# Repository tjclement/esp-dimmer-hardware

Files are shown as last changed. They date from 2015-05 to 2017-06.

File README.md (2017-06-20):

# $5 ESP8266 WiFi LED Dimmer
Custom hardware designs for a super tiny WiFi LED dimmer module based on the ESP8266, to control your lights from any device. __Doesn't need any arduinos or raspberries to work, just the ESP__. If you like this, please give it a star!

__Update:__ The new module design for RGB (i.e. triple channel) LEDs is done. This new design can handle up to ~8.5A of current per channel! Its parts costs the same as the old design, and if you want only one channel, you could just not solder the 2nd and 3rd channel. This way you can use the beefed up design. :)

<p align="center">
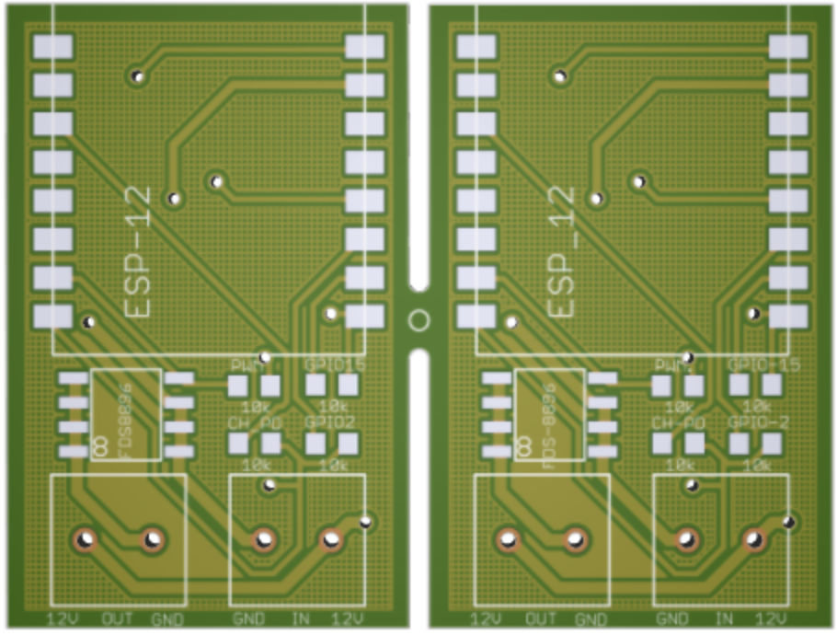
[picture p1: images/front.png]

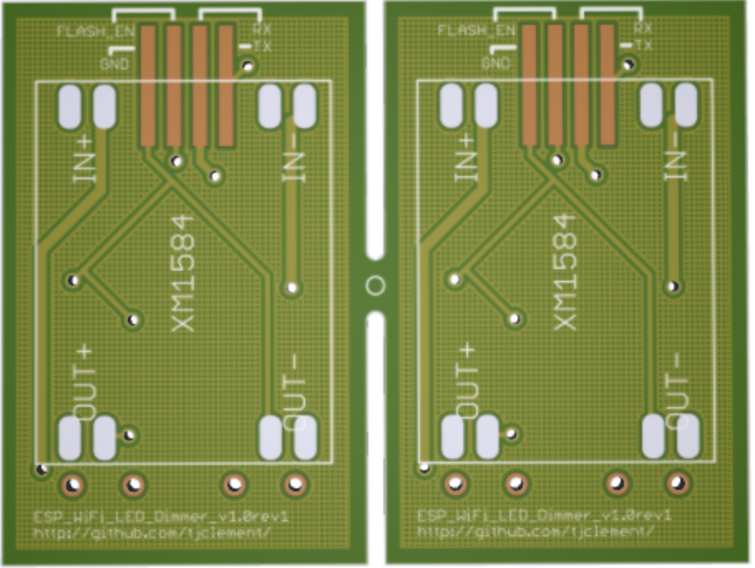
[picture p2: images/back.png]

</p>
<p align="center">
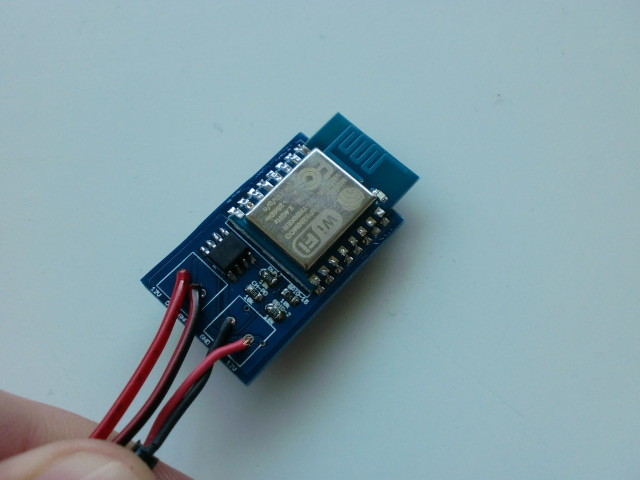
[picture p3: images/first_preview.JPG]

</p>

# Ordering the board
Choose whether you want a single or triple channel dimmer, and then send all files in [single_channel or triple_channel]/gerber_files/ to your PCB house, and all should be fine and dandy!

You can also order the new triple channel design from DirtyPCBs here: 
http://dirtypcbs.com/store/designer/details/tjclement/1329/5-esp8266-rgb-led-dimmer

# Parts
After having ordered the print board, you're going to want to have these parts for every module (mind you, there's two panelized modules per board ordered!):
<table>
  <tr>
    <td colspan="2"><strong>Single Channel (old version)</strong></td>
    <td colspan="2"><strong>Triple Channel (new version)</strong></td>
  </tr>
  <tr>
    <td>Amount</td>
    <td>Description</td>
    <td>Amount</td>
    <td>Description</td>
  </tr>
  <tr>
    <td>1</td>
    <td>ESP8266, ESP-12(E) format</td>
    <td>1</td>
    <td>ESP8266, ESP-12(E) format</td>
  </tr>
  <tr>
    <td>1</td>
    <td>XM1584 Power converter (set to 3.3v!)</td>
    <td>1</td>
    <td>MP2307 MINI 360 Power converter (3.3v!)</td>
  </tr>
  <tr>
    <td>1</td>
    <td>FDS8896 PowerTrench MOSFET</td>
    <td>3</td>
    <td>FDS8896 PowerTrench MOSFET</td>
  </tr>
  <tr>
    <td>2</td>
    <td>KF350-2P screw terminal blocks</td>
    <td>4</td>
    <td>KF350-2P screw terminal blocks</td>
  </tr>
  <tr>
    <td>4</td>
    <td>10k resistors, 0603 format</td>
    <td>6</td>
    <td>10k resistors, 0603 format</td>
  </tr>
</table>

__Total cost: less than $5!__

I order most of it from China, sites like aliexpress.com will have everything you need.

# Firmware
Because this module is essentially a breakout for the ESP8266, you can use any firmware written for it.
I've written a bunch of cool things to get this module running as I want it to, check it out here: http://github.com/tjclement/esp-dimmer-software.

Just hook up a 12V power supply, connect it and the LED strip to the module, and the ESP will be able to control the LEDs. Awesome!

If you're looking for something else (or write your own firmware), have a look at http://esp8266.com for more resources.

You can use a loader like this one to load firmware onto the ESP: https://github.com/themadinventor/esptool.

# Contributing
You can open the .sch and .brd files in Eagle (V7.2+), and make any modifications you see fit. If you add something cool, please create a pull request so we can bring the awesomeness into the community!

# Credits
Heavily inspired by Quindor's original design over at http://blog.quindorian.org/2014/12/esp8266-wifi-led-dimmer-part-1-of-x.html/. We've been sharing design ideas back and forth ever since. Nice job mate!

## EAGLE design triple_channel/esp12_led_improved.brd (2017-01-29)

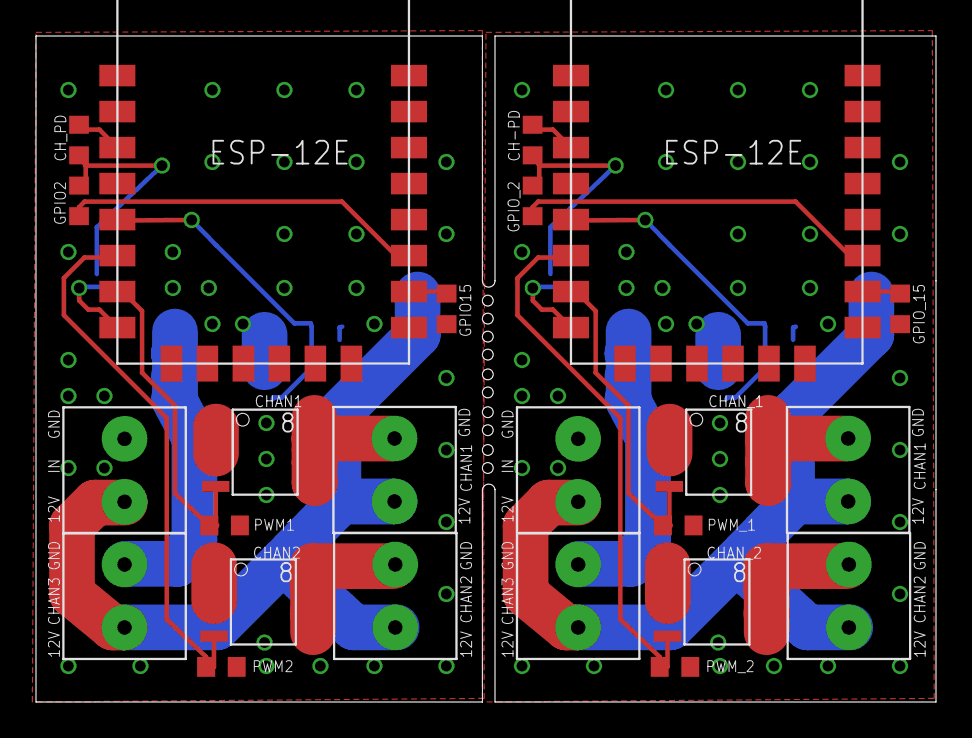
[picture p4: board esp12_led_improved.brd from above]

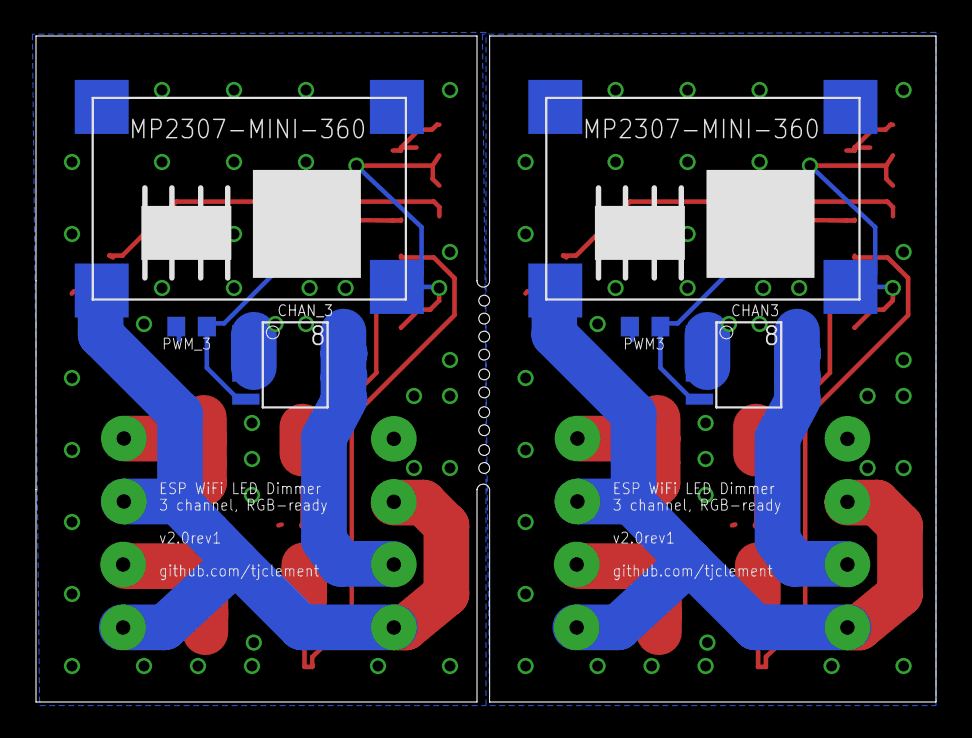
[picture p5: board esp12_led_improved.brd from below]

Board: 2 copper layers, 50.0 x 37.0 mm, 30 parts (6 on the bottom side), 26 nets.

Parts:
CH-PD: 10K; R0603
CHAN1, CHAN2, CHAN3: SO-8
CHAN_1, CHAN_2, CHAN_3: SO-8
CH_PD: 10K; R0603
GPIO2, GPIO15: 10K; R0603
GPIO_2, GPIO_15: 10K; R0603
OUT1, OUT2, OUT3, OUT4, OUT5, OUT6: KF350-P2; KF350-2P
PWM1, PWM2, PWM3: 10K; R0603
PWM_1, PWM_2, PWM_3: 10K; R0603
PWR1, PWR2: MP2307-MINI-360
PWR_IN, PWR_IN1: KF350-P2; KF350-2P
XXX, XXX1: ESP8266-ESP12E

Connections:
3.3V: CH_PD.1, GPIO2.1
3.3V1: CH-PD.1, GPIO_2.1
12V: OUT1.1, OUT2.1, OUT3.1, PWR1.12V, PWR_IN.1
12V1: OUT4.1, OUT5.1, OUT6.1, PWR2.12V, PWR_IN1.1
GND: CHAN1.1, CHAN1.2, CHAN1.3, CHAN2.1, CHAN2.2, CHAN2.3, CHAN3.1, CHAN3.2, CHAN3.3, GPIO15.2, PWM1.2, PWM2.2, PWM3.2, PWR1.GND@1, PWR1.GND@2, PWR_IN.2, XXX.9
GND1: CHAN_1.1, CHAN_1.2, CHAN_1.3, CHAN_2.1, CHAN_2.2, CHAN_2.3, CHAN_3.1, CHAN_3.2, CHAN_3.3, GPIO_15.2, PWM_1.2, PWM_2.2, PWM_3.2, PWR2.GND@1, PWR2.GND@2, PWR_IN1.2, XXX1.9
unnamed: CHAN1.5, CHAN1.6, CHAN1.7, CHAN1.8, OUT1.2
unnamed: CH-PD.2, XXX1.3
unnamed: CH_PD.2, XXX.3
unnamed: GPIO2.2, XXX.11
unnamed: CHAN_1.5, CHAN_1.6, CHAN_1.7, CHAN_1.8, OUT4.2
unnamed: CHAN1.4, PWM1.1, XXX.7
unnamed: CHAN2.5, CHAN2.6, CHAN2.7, CHAN2.8, OUT2.2
unnamed: GPIO_2.2, XXX1.11
unnamed: CHAN3.5, CHAN3.6, CHAN3.7, CHAN3.8, OUT3.2
unnamed: CHAN_1.4, PWM_1.1, XXX1.7
unnamed: CHAN2.4, PWM2.1, XXX.6
unnamed: CHAN3.4, PWM3.1, XXX.5
unnamed: CHAN_2.5, CHAN_2.6, CHAN_2.7, CHAN_2.8, OUT5.2
unnamed: CHAN_3.5, CHAN_3.6, CHAN_3.7, CHAN_3.8, OUT6.2
unnamed: CHAN_2.4, PWM_2.1, XXX1.6
unnamed: CHAN_3.4, PWM_3.1, XXX1.5
S$1: PWR1.3.3V, XXX.8
S$2: GPIO15.1, XXX.10
S$3: PWR2.3.3V, XXX1.8
S$4: GPIO_15.1, XXX1.10

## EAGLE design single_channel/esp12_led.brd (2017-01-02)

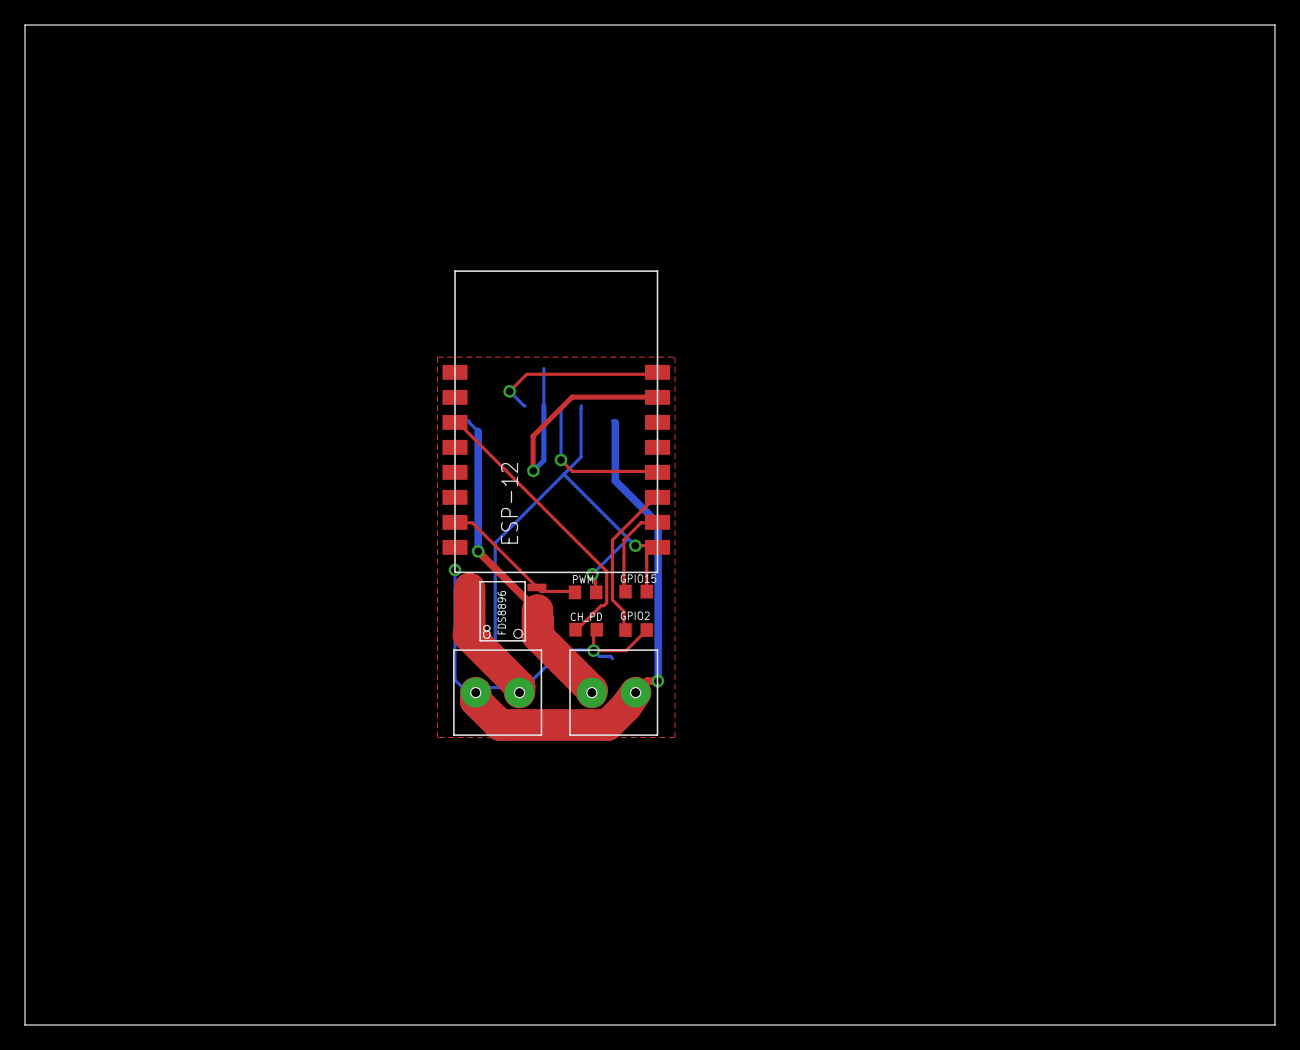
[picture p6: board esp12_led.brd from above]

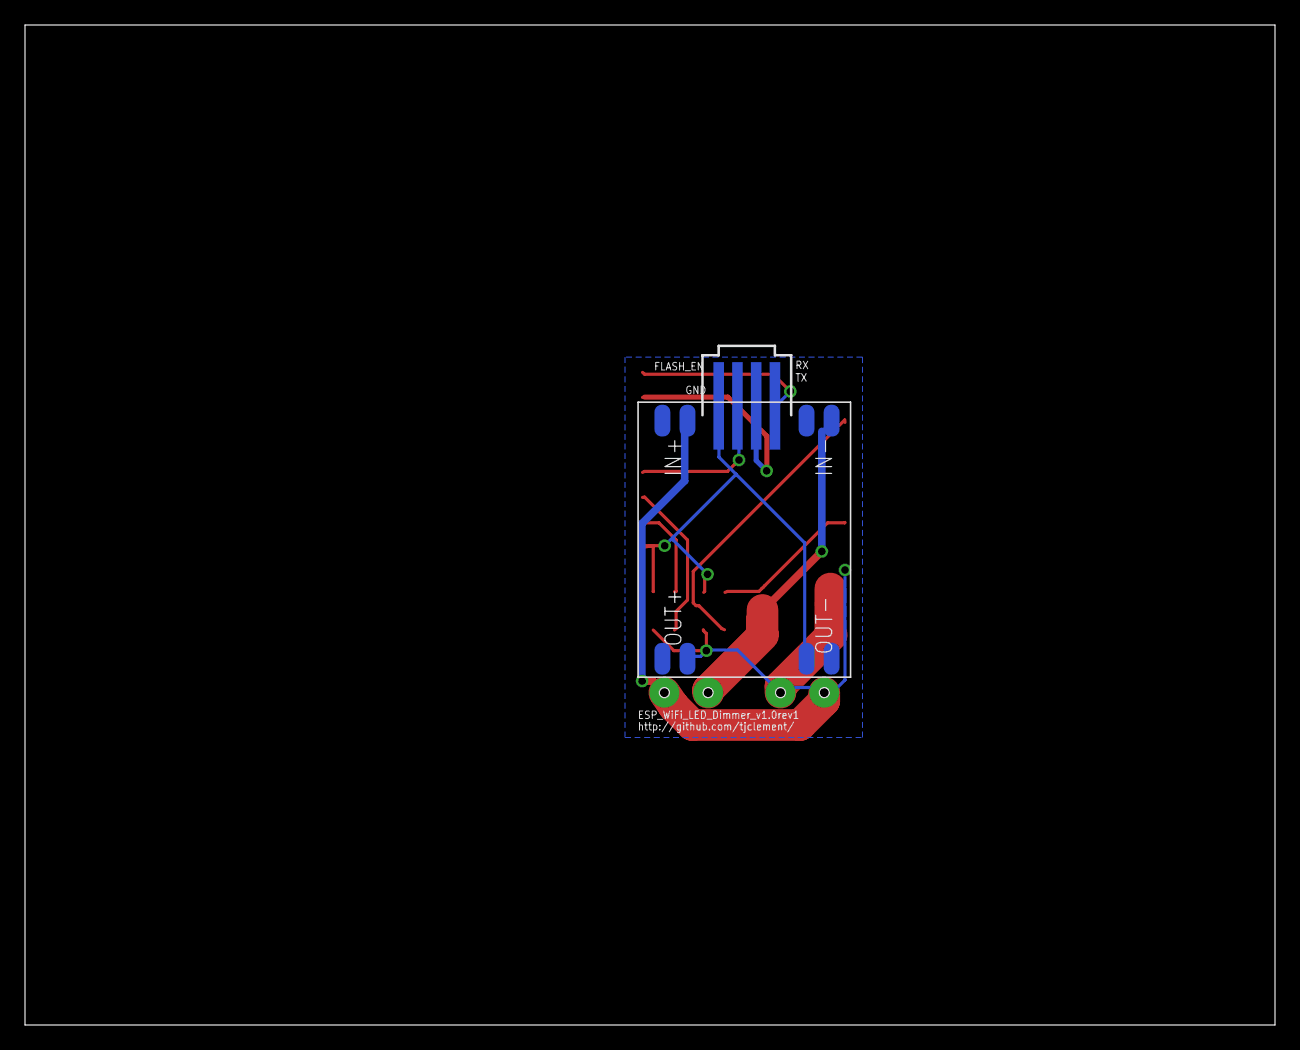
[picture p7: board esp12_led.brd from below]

Board: 2 copper layers, 100.0 x 80.0 mm, 10 parts (2 on the bottom side), 13 nets.

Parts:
12V_IN: KF350-P2; KF350-2P
CH_PD: 10k; R0603
DC_CONVERTER: CN1594THROUGH-HOLE; CN1594
ESP-12: ESP8266_ESP-12; ESP8266-ESP12
FDS8896: SO-8
GPIO2, GPIO15: 10k; R0603
LED: KF350-P2; KF350-2P
PROG: 87438-04
PWM: 10k; R0603

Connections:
unnamed: CH_PD.2, DC_CONVERTER.OUT+(1), ESP-12.16, GPIO2.2
unnamed: CH_PD.1, ESP-12.11
unnamed: ESP-12.3, GPIO2.1
unnamed: FDS8896.5, FDS8896.6, FDS8896.7, FDS8896.8, LED.2
unnamed: ESP-12.8, PROG.1
unnamed: DC_CONVERTER.OUT-(2), ESP-12.1, GPIO15.2, PROG.4, PWM.2
unnamed: ESP-12.2, GPIO15.1
unnamed: ESP-12.7, PROG.2
unnamed: ESP-12.4, PROG.3
unnamed: DC_CONVERTER.IN-(1), FDS8896.3
unnamed: 12V_IN.2, DC_CONVERTER.IN+(1), LED.1
S$2: ESP-12.15, FDS8896.4, PWM.1
S$3: 12V_IN.1, FDS8896.1, FDS8896.2

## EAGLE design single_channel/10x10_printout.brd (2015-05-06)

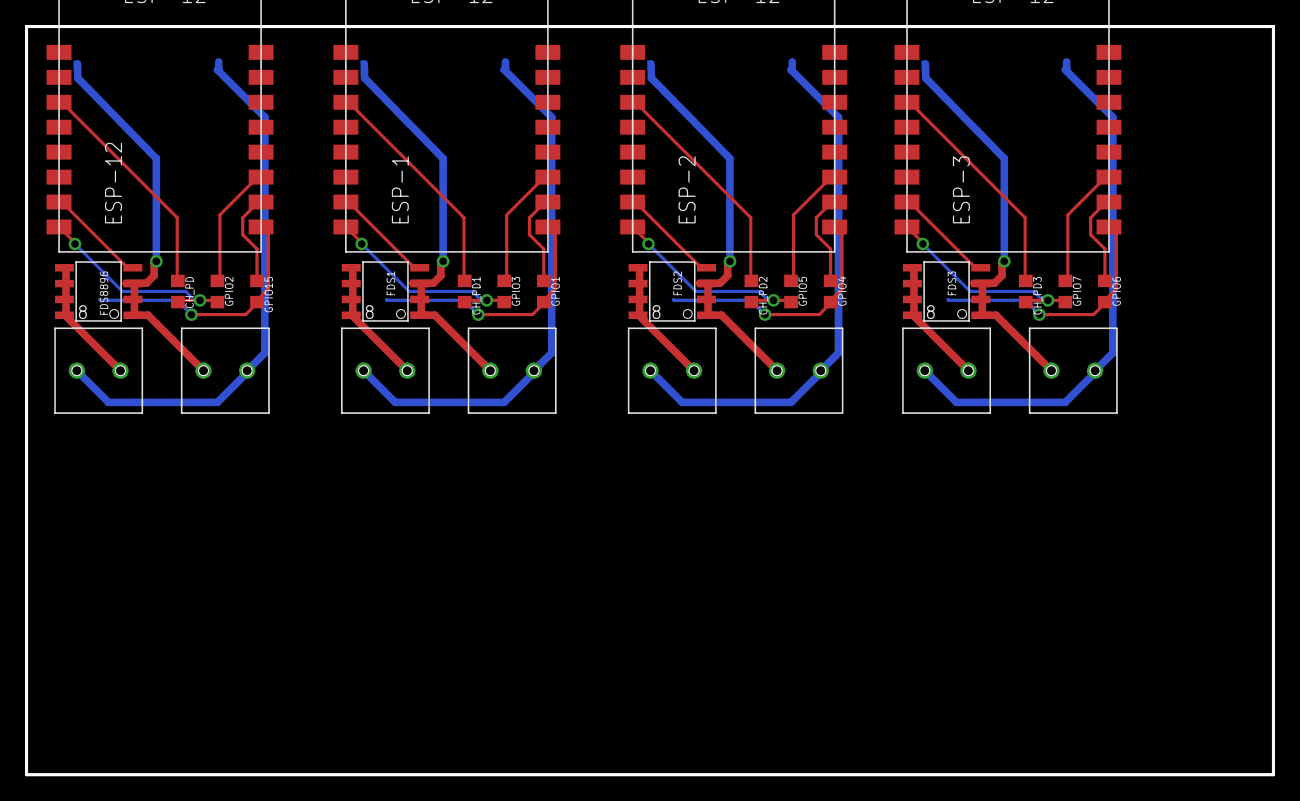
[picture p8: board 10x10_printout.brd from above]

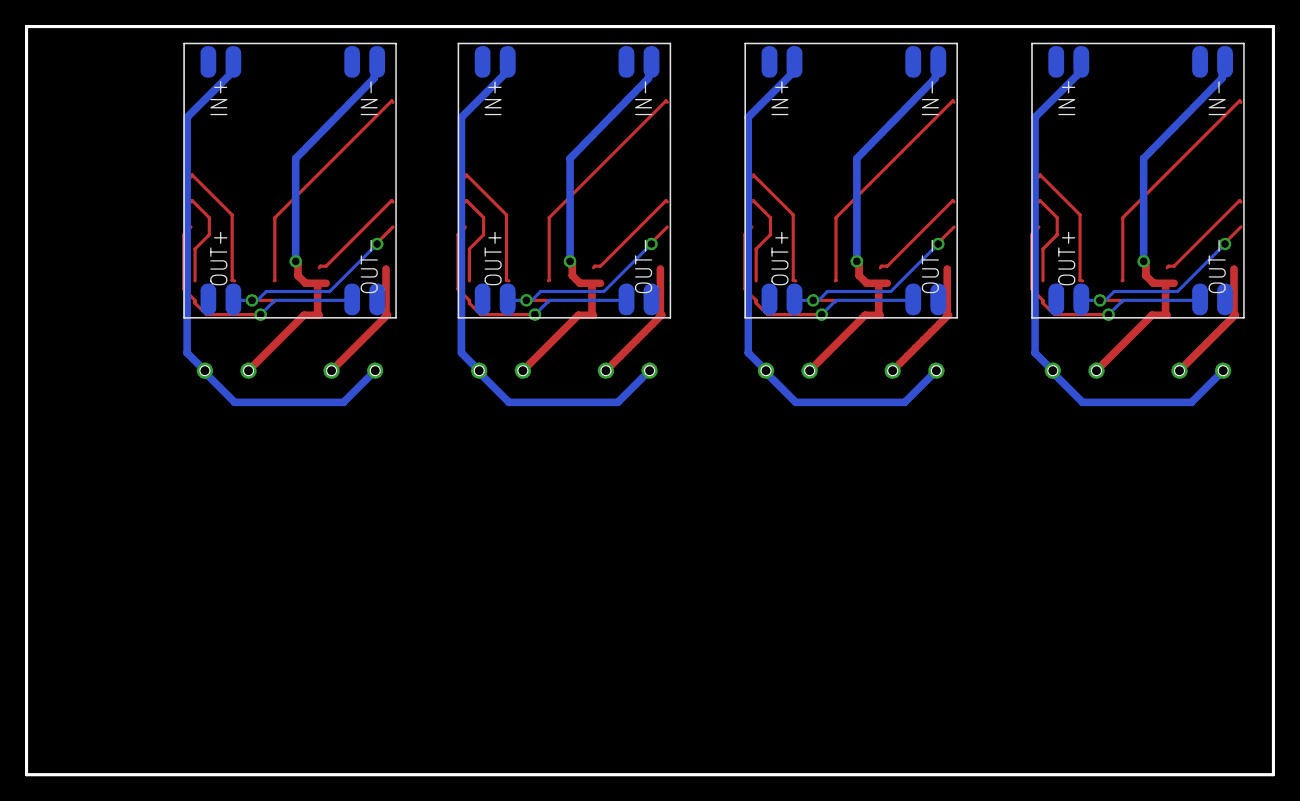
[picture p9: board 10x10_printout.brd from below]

Board: 2 copper layers, 100.0 x 60.0 mm, 32 parts (4 on the bottom side), 36 nets.

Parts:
12V_IN, 12V_IN1, 12V_IN2, 12V_IN3: KF350-P2; KF350-2P
CH_PD, CH_PD1, CH_PD2, CH_PD3: 10k; R0603
ESP-1, ESP-2, ESP-3, ESP-12: ESP8266_ESP-12; ESP8266-ESP12
FDS1, FDS2, FDS3, FDS8896: SO-8
GPIO1, GPIO2, GPIO3, GPIO4, GPIO5, GPIO6, GPIO7, GPIO15: 10k; R0603
LED, LED1, LED2, LED3: KF350-P2; KF350-2P
U$1, U$2, U$3, U$4: CN1594THROUGH-HOLE; CN1594

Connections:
unnamed: CH_PD.2, ESP-12.16, GPIO2.2, U$2.OUT+(1)
unnamed: CH_PD.1, ESP-12.11
unnamed: ESP-12.3, GPIO2.1
unnamed: FDS8896.5, FDS8896.6, FDS8896.7, FDS8896.8, LED.2
unnamed: CH_PD1.2, ESP-1.16, GPIO3.2, U$1.OUT+(1)
unnamed: ESP-12.1, GPIO15.2, U$2.OUT-(2)
unnamed: ESP-12.2, GPIO15.1
unnamed: CH_PD1.1, ESP-1.11
unnamed: ESP-1.3, GPIO3.1
unnamed: 12V_IN.1, FDS8896.1, FDS8896.2, FDS8896.3, U$2.IN-(1)
unnamed: ESP-12.15, FDS8896.4
unnamed: 12V_IN.2, LED.1, U$2.IN+(1)
unnamed: ESP-1.1, GPIO1.2, U$1.OUT-(2)
unnamed: ESP-1.2, GPIO1.1
unnamed: FDS1.5, FDS1.6, FDS1.7, FDS1.8, LED1.2
unnamed: ESP-1.15, FDS1.4
unnamed: 12V_IN1.1, FDS1.1, FDS1.2, FDS1.3, U$1.IN-(1)
unnamed: 12V_IN1.2, LED1.1, U$1.IN+(1)
unnamed: CH_PD2.2, ESP-2.16, GPIO5.2, U$3.OUT+(1)
unnamed: CH_PD2.1, ESP-2.11
unnamed: ESP-2.3, GPIO5.1
unnamed: ESP-2.1, GPIO4.2, U$3.OUT-(2)
unnamed: ESP-2.2, GPIO4.1
unnamed: FDS2.5, FDS2.6, FDS2.7, FDS2.8, LED2.2
unnamed: ESP-2.15, FDS2.4
unnamed: 12V_IN2.1, FDS2.1, FDS2.2, FDS2.3, U$3.IN-(1)
unnamed: 12V_IN2.2, LED2.1, U$3.IN+(1)
unnamed: CH_PD3.2, ESP-3.16, GPIO7.2, U$4.OUT+(1)
unnamed: CH_PD3.1, ESP-3.11
unnamed: ESP-3.3, GPIO7.1
unnamed: ESP-3.1, GPIO6.2, U$4.OUT-(2)
unnamed: ESP-3.2, GPIO6.1
unnamed: FDS3.5, FDS3.6, FDS3.7, FDS3.8, LED3.2
unnamed: ESP-3.15, FDS3.4
unnamed: 12V_IN3.1, FDS3.1, FDS3.2, FDS3.3, U$4.IN-(1)
unnamed: 12V_IN3.2, LED3.1, U$4.IN+(1)

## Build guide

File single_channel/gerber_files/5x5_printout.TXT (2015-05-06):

%
M48
M72
T01C0.02400
T02C0.03150
%
T01
X10475Y6374
X12214Y8911
X13085Y9254
X11465Y11414
X15425Y6554
X14075Y5654
X14165Y3044
X16134Y2290
X5504Y3044
X7473Y2290
X5414Y5654
X6764Y6554
X4424Y9254
X3552Y8911
X2804Y11414
X1814Y6374
T02
X10399Y1926
X10399Y1926
X11777Y1926
X11777Y1926
X14056Y1926
X14056Y1926
X15434Y1926
X15434Y1926
X1737Y1926
X1737Y1926
X3115Y1926
X3115Y1926
X5395Y1926
X5395Y1926
X6773Y1926
X6773Y1926
M30

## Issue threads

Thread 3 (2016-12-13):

What GPIO is used to control PWM?

ArnieX, 2016-12-13:
Hi @tjclement,

which GPIO is used for PWM?

I have just built it myself and it is awesome little board!

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

Thank you,

Martin

tjclement, 2016-12-14:
Hi @ArnieX,

Your module looks great, nice job!

You can check out the example software I wrote for this board [here](https://github.com/tjclement/esp-dimmer-software/). The GPIO used is the ESP's pin 13; if you're using nodeMCU, [this pin is called pin 7](https://github.com/tjclement/esp-dimmer-software/blob/master/pwmServer.lua#L7).

Good luck, and have fun!

Best,
Tom

ArnieX, 2016-12-14:
Hi @tjclement,

thank you for the quick response. Unfortunately my module had died before I was able to do some serious things. I have no idea what happened and today I fly out to business trip. Have you had similar issue yourself? Now it doesn't even light the strip when connected nor start ESP up. Could that be fried mosfet? How do you exactly set the voltage? I did it to 3.30xV. Do you glue the screw so it couldn't accidantaly change?

Thank you for some hints.

Martin

tjclement, 2016-12-18:
The ESP datasheet mentions a maximum input voltage of 3.6v, so I set it to ~3.4v. Anecdotally, this increases the chip's stability. Your setting of 3.3v should be fine though, and is definitely not the cause of it not functioning anymore.

I've had failing ESPs on a few of my modules, mostly because of incorrectly set voltage converter settings. Like you said, putting a drop of hot glue on the screw of the voltage converter helps with this problem. I've also had a software issue once that made the device enter a boot loop, which I didn't notice for several hours. This increased its temperature so much it must have overheated. It was unresponsive afterwards.

If the blue LED on the ESP still blinks when you power on your module, the MOSFET or any of the PCB traces may have been fried. If the blue LED doesn't turn on at all, check if the voltage converter still outputs enough volts. If the blue LED remains on continuously, or the ESP gets very hot without doing anything, your ESP has been fried for some reason. If you find out what's wrong, please leave another comment. Perhaps we can improve the module design!

Also related, I'm working on a new version of this board that is even smaller and has 3 channels instead of 1. This allows for dimming traditional RGB LED strips. I've not pushed this to the master branch yet because the design is untested, but I'll push them to a seperate branch when I have a moment. You may find it interesting to look at, too.

ArnieX, 2016-12-18:
Hi Tom,

here is the firmware https://github.com/ArnieX/esp-dimmer-firmware

BR,

Martin

RiRomain, 2016-12-19:
@tjclement I've already made a fork of your project and made an RGB driver out of your board :-) :
https://github.com/RiRomain/esp-dimmer-hardware
I've already assemble some unit and it works great for more than a year now! Thanks you for your design.

Closed 2016-12-14.

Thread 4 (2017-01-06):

Programming interface

ArnieX, 2017-01-06:
Hi @tjclement,

good job with the new version, I will likely order it just to have few boards at home. Good to see that you have made contact pads for DC-DC converter much bigger. What am I missing thought are pins for programming the esp. Sometimes there is need to connect it by cable, at least for first flashing. Is it missing by design or did you forget it? Is there place to add it? I would definitely love at least contacts like on the first module but this time with 2.54 pitch so I can snap or solder 2.54 header directly without modification.

Best regards,

Martin

tjclement, 2017-01-08:
Hi @ArnieX,

The flashing pins on the original design didn't work that well for me. It took a lot of tries to flash the module, each time failing when it was around 90% done flashing.

That, combined with the fact I'd like to replace the ESP chip on the module if it ever breaks down, instead of having to bin the entire module, I ended up soldering 2mm headers on my modules like this:

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

The ESP can be placed on the headers without soldering, and when you want to (re)flash them, just put them on a separate programmer module that has the same exposing headers:

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

This setup worked very well for me in the first design, so I chose not to have any programming pins exposed in the second design.

What do you think?

ArnieX, 2017-01-08:
Hi @tjclement,

well on previous module it worked perfectly, at least for me. I would also add 3,3V IN so you do not need to connect 12V IN but otherwise it was OK. Problem with your ideas, illustrated by the images you share is that it is good for prototyping, but not really for final module with everything soldered. On our device (but it is a lot bigger) we have made accessible header for programming like this image shows.

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

It is similar to your solution but allow for ESP to be soldered directly on it, gives it also power from regulator on NodeMCU. So that you do not need to connect it to mains while flashing the firmware. From our experience ESP don't break that easily, actually we haven't yet have any failing.

Here is the scheme for our programming interface:

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

and if other UART USB2SERIAL is used instead of NodeMCU we have jumper to enable flash mode:

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

Maybe you could find a way how to get it on your module too, even-thought it is lot more crowded. Otherwise I have already ordered more transistors and the new mini360 power so I can order new modules to test them. BTW my colleague had a great idea to make the programming interface to fit female USB-A but it would need holes to fix it, contact pads could be bent to be soldered on surface contacts. Then you would just hack USB cable to connect to UART USB2SERIAL programmer.

[USB-A AliExpress](https://www.aliexpress.com/item/10PCS-USB-type-A-USB-mother-Curved-needle/32265708803.html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,searchweb201602_2_10065_10068_10000009_10084_10083_10080_10082_10081_10060_10062_10056_10055_10037_10054_10033_10059_10032_10099_10078_10079_10077_10000012_426_10103_10073_10102_10000015_10096_10052_10053_10107_10050_10106_10051,searchweb201603_10,afswitch_5,single_sort_0_default&btsid=8af59f64-a330-4f4f-be2b-329c17f3dfab)

That is just one of the ideas. Nothing will be perfect but I would rather have something than nothing ;)

Let me know if I can do more for you,

Martin

ArnieX, 2017-01-28:
Thanks for the idea with flashing socket from NodeMCU, it works flawlessly.

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

Closed 2017-04-12.

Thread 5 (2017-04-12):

Copper on PCB

Aertbei, 2017-04-12:
Is it necessary to order the PCB with 2 oz copper or is 1 oz fine?

tjclement, 2017-04-12:
1 oz is fine, with this you should have a theoretical limit of 8A of power before the traces reach temps of over 65 degrees Celsius.

If you go with 2 oz, you'd even be able to approach the 15A limit of the FDS8896 mosfet. This is cool, but by no means necessary.

Thanks for reaching out, have fun!

tjclement, 2017-04-12:
If you plan on having large currents run through the module, by the way, be sure to use the new triple channel design. This has beefed up traces that allow for the 8A I mentioned above.

The previous single channel design is rated for much less (~2.5A).

Closed 2017-04-12.

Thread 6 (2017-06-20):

Link to DirtyPCB is not accessible

RiRomain, 2017-06-20:
The link under **Ordering the board** redirect to dirty PCB shop but not to your design (http://dirtypcbs.com/store/designer/details/tjclement/1218/esp12-led-improved-zip)

I found the board in the dirty board shop at the address:
http://dirtypcbs.com/store/designer/details/tjclement/1329/5-esp8266-rgb-led-dimmer

BTW thanks for this great work I'll order one set :+1:

tjclement, 2017-06-20:
Thanks for letting me know. Glad to hear you like it, have fun building them!

Closed 2017-06-20.

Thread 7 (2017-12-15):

Flickering with PWM

TMaYaD, 2017-12-15:
How are you addressing the flickering due to lack of hardware pwm on esp8266?

tjclement, 2017-12-15:
The esp does have hardware PWM, and it is supported in the Arduino API, the FreeRTOS release, and the esp IoT framework.

I'm currently using the Arduino API. It has a default PWM frequency of 1kHz, which is more than enough for simple, non-moving room lighting. You can increase the frequency, at cost of stepping precision (analogWriteFreq()).

TMaYaD, 2017-12-16:
Oh, Thank you for making that clear.

Closed 2017-12-15.

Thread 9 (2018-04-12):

Add microwave motion detector and brightness/color sensor

renne, 2018-04-12:
I suggest to add a 0,40 $ [RCWL-0516](https://github.com/jdesbonnet/RCWL-0516) microwave motion detector to a GPIO of the ESP8266 and an 2,- $ [APDS-9960](https://cdn.sparkfun.com/datasheets/Sensors/Proximity/apds9960.pdf) brightness/color sensor via I2C.

That way the LED-controller can switch the light on if there is movement in the room. The [APDS-9960](https://cdn.sparkfun.com/datasheets/Sensors/Proximity/apds9960.pdf) can be used to detect current brightness and color temperature in the room for closed-loop brightness/color control.

The gesture support of the [APDS-9960](https://cdn.sparkfun.com/datasheets/Sensors/Proximity/apds9960.pdf) can be used for dimming and changing the color temperature.

[APDS-9960 Arduino-library](https://github.com/sparkfun/SparkFun_APDS-9960_Sensor_Arduino_Library/tree/V_1.4.2)

tjclement, 2018-04-12:
Sweet idea. I'll expose the necessary GPIO pins on the next iteration of the module. Thanks ;)

hnykda, 2021-05-30:
:wave: wanted to ask if you plan to ever update it or not anymore? :upside_down_face:

tjclement, 2021-05-30:
I might, if enough people are interested in a new version. I've learned a lot in the 5 years since I made this design, so I'm sure it could be improved even further. :)

Closed 2022-11-21.

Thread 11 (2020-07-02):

MOSFET gate resistor position in Version 2 schematic

danricho, 2020-07-02:
I believe that your schematic needs correction in the version 2.
They show as in series between the ESP and the mosfets, but I think they are meant to be pull-down.

I have made my own version with a few additions [here](https://github.com/danricho/ESP8266_12VLED_Driver/).

Great design and thanks!

tjclement, 2020-07-02:
Hey, thanks for reaching out! The resistors there are current-limiting to prevent damage to the ESP should the mosfet fail closed. There should also be pulldowns to prevent flickering during booting of the ESP, you're right. During normal operation this doesn't matter too much, since the GPIOs are actively driven.

Your version looks good, nice work! I might update my design sometime in the future too.

danricho, 2020-07-02:
Fair enough. The first version of my PCB had the inline resistor only and the output wasn’t stable... I’m unsure what I did wrong as it was exactly the same as your PCB schematically... and I didn’t have that issue with yours (which I used for a year+). The updated version I’ve shared, seems to work but I didn’t consider the failure modes of the MOSFET!

Again, thanks for sharing your design!

Closed 2020-07-02.

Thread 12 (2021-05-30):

Support for 24V LED

hnykda, 2021-05-30:
Hey. I am really excited about this project as I want to be able to individually control many different light strips in my home run in parallel in different temperatures.

I have two questions:

1. can the board be edited in a way that it supports 24V LED strips or do I need some buck converter (which would be pretty annoying if I had to do it for each channel individually)?
2. I really just order it from http://dirtypcbs.com/store/designer/details/tjclement/1329/5-esp8266-rgb-led-dimmer (e.g. in 10 pieces), buying [these](http://dirtypcbs.com/store/designer/details/tjclement/1329/5-esp8266-rgb-led-dimmer) from e.g. aliexpress, solder it on the board, use ESPHome to flash it (after connecting it via serial-to-USB to PC)  and then I am done? Living a dream :scream: .

Thanks for an amazing work!

tjclement, 2021-05-30:
Hey, thanks for reaching out. Cool to see you're interested in making some!

To answer your questions:

1. In theory the FDS8896 mosfet can handle 24V just fine, although the MP2307 buck converter is listed as 23V max input. I've not tested at 24V; you could try your luck and see if it works.

At the least it's assumable that the lifespan of the buck converter is reduced when you feed it 24V, although whether I don't know whether it'll be significant. You could also try to find alternative buck converters for which 24V is within their operating range, and e.g solder them to the board with. wires.

2. Yep, that's it. The components you'll need are on the main readme in this repository:
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. For the resistors, it helps to get some tweezers to keep them in place during soldering.

Good luck, and enjoy!

Closed 2021-05-30.

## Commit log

2015-05-06 Initial fill, v1.0rev1
    [10x10_printout.brd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]
2015-05-06 Added image preview of board
2017-01-02 Improved design: Added triple channel (RGB) support, beefed up to ~8.5A per channel.
    [10x10_printout.brd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]
2017-01-29 Fixed PWM resistors being applied in series instead of as pulldowns
    [esp12_led_improved.GBL, esp12_led_improved.GBO, esp12_led_improved.GBP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]
